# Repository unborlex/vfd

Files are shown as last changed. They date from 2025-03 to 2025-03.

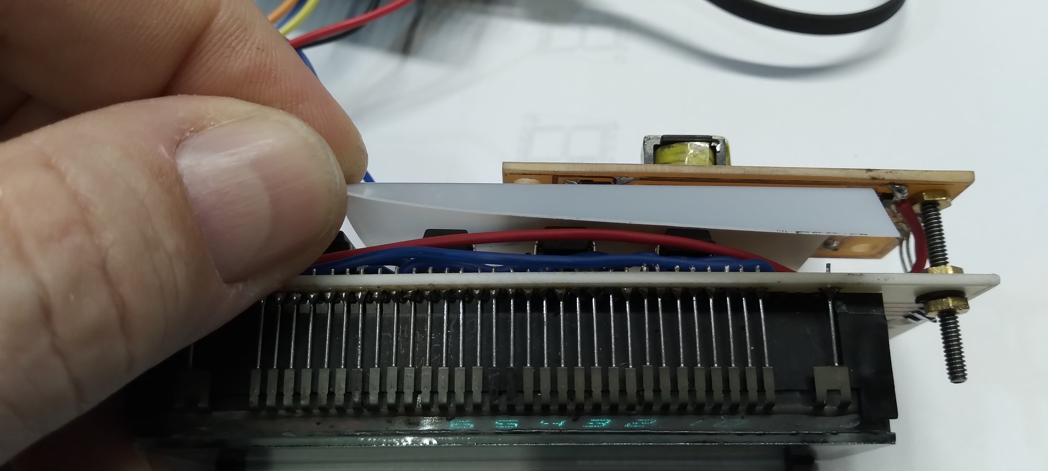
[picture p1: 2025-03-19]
20250319_105229.jpg

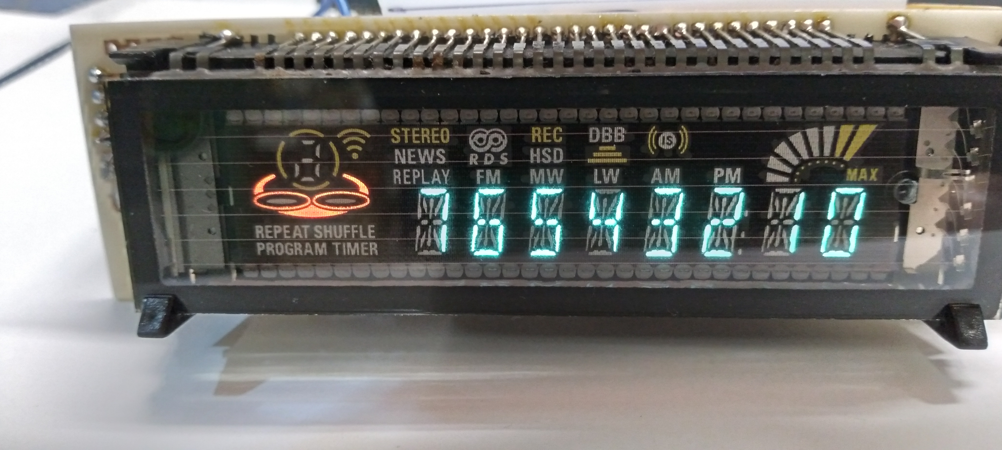
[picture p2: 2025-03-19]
20250319_105207.jpg

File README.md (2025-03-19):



El soft esta generado para arduino, en un ESP32, hay dos funciones principales para escribir en el display solo numeros y una es para escribir 8 digitos mas uno de simbolos 
y otra funcion donde se pueden escribir 4 digitos, en este caso se obtiene el doble de brillo ya que solo se multiplexa por 4.

La electronica consta de registros de dezplazamiento CD4094 funcionando en 18,5V elevando los 5V del ESP32 con un MC34063 y aislando las entradas con transistores para funcionar con 
señales de 3v del ESP32.

El filamento es alimentado con una tension cuadrada bipolar generada por un CD40106 montada sobre los 5V ( de 0,7 a 4,3V ) variable con un potenciometro, este valor queda montado por debajo de los 5v
de esta forma cuando los anodos y las grillas tienen 0v se logra un apagado total de los mismos y con la alterna se logra un brillo mas parejo a lo largo del display.

La tension de 18v tambien puede variarse con un potenciometro, la realidad es que la tension de filamento en mi display hay que mantenerla el maximo y la tension de anados y grilla 
tambien estan al maximo en mi caso 18,5v.

Usando estos integrados no debemos superar los 20V, no llegue a probar esto, esta circuiteria y soft es un prototipo de prueba para este display en particular, otros modelos deberan ser
ensayados con otros tipos de circuitos a medida.
La tension de funcionamiento ideal seria un poco mas elevada 25-35V el problema es que habria que usar un conjunto de transistores y resistencias por pin de anodo y grilla ya que los CMOS se quemarian, multiplicando la electronica demasiado, todo esto para obtener un display que podria ser reemplazado tranquilamente por uno alfanumerico de 2x16 caracterers

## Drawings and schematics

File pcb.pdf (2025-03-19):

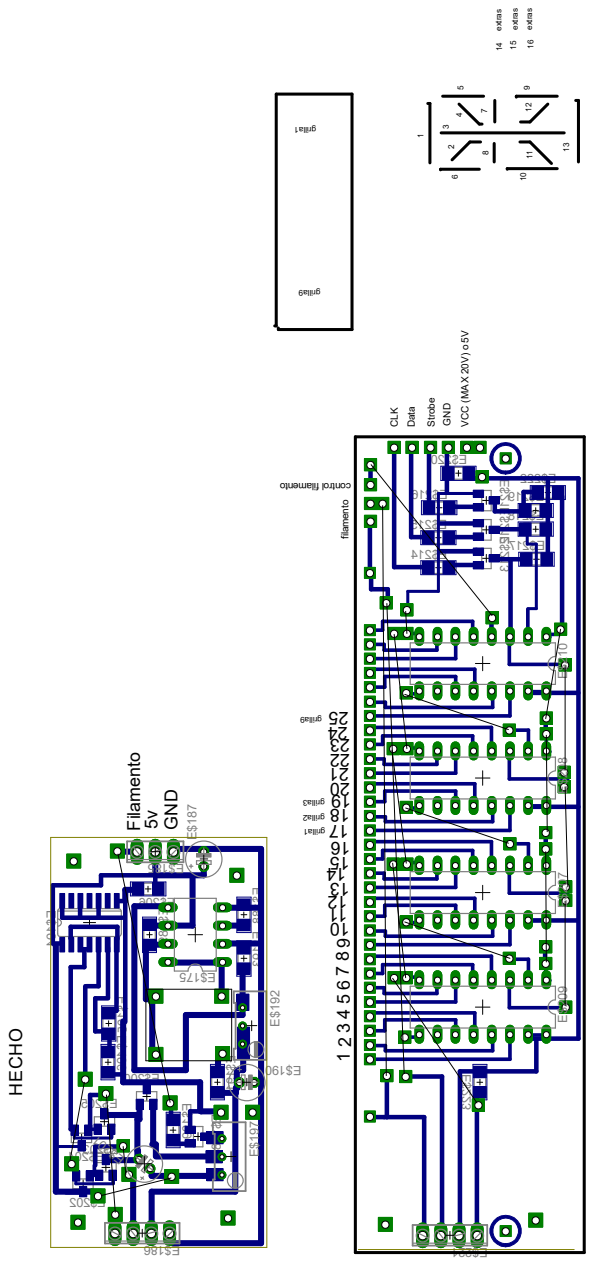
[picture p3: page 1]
grilla1; grilla2; grilla3; grilla9

9 10 11 12 13 141516 extras extras extras

E$221 Filamento 5vGND HECHO filamento control filamento CLK Data Strobe GND VCC (MAX 20V) o 5V

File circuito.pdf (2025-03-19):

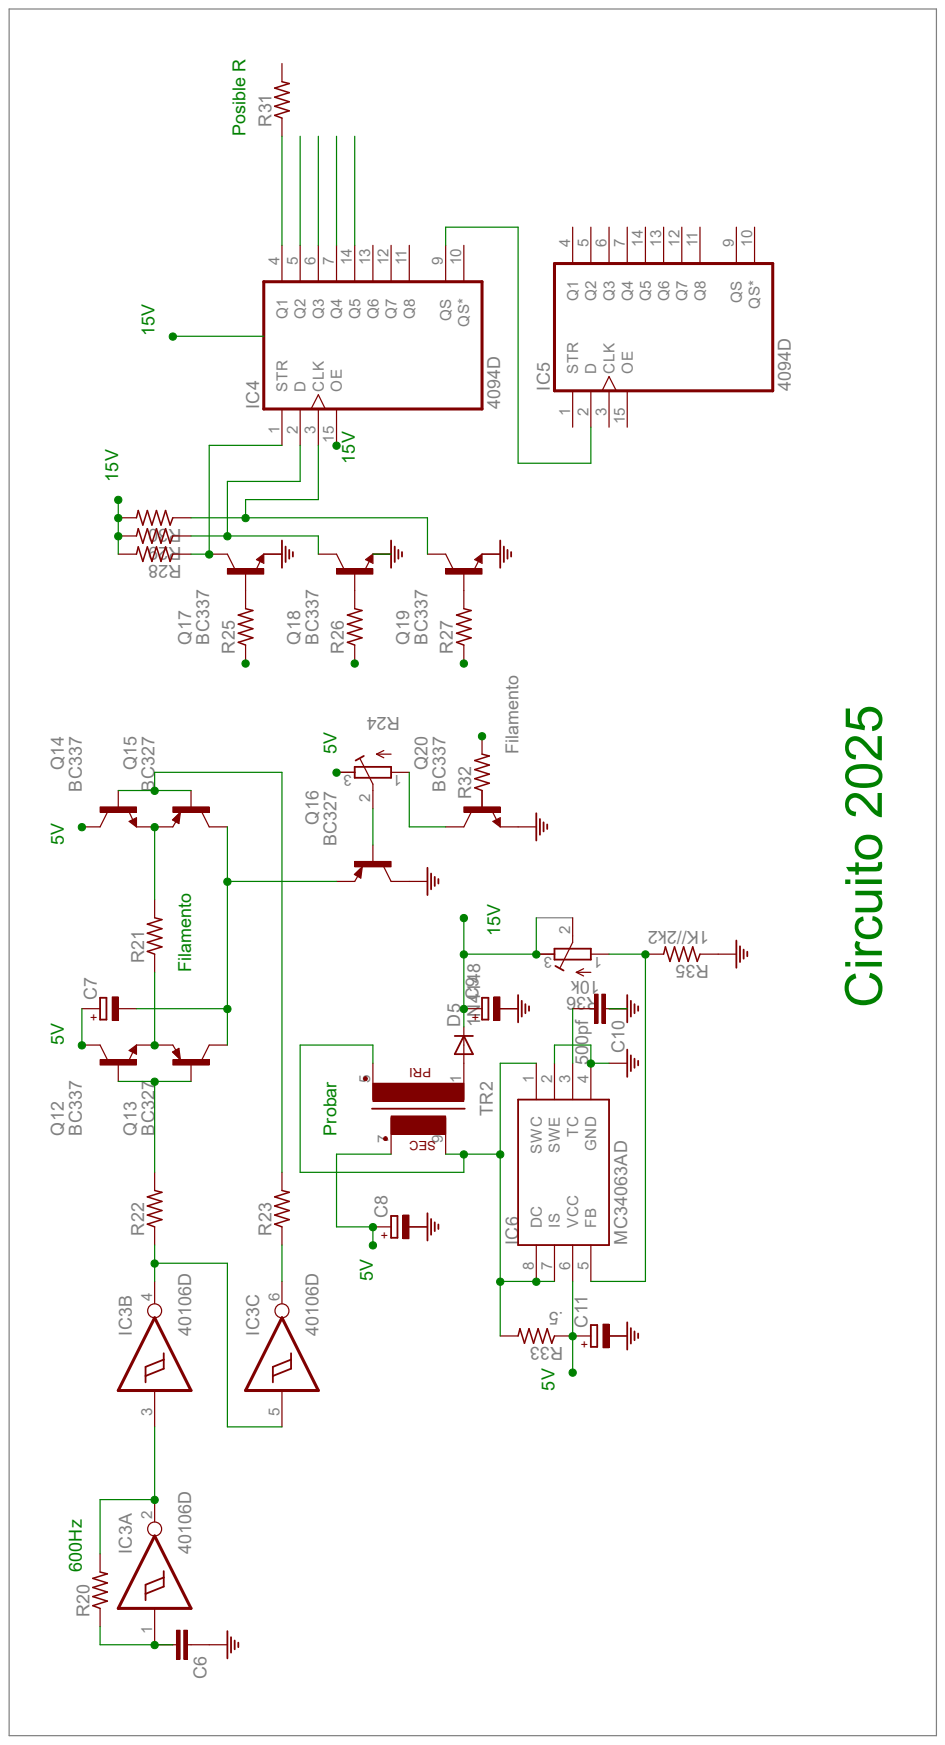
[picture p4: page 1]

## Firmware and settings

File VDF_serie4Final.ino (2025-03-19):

void          demo_var();
void          visualizar9();
void          apagado();
void          visualizar4();


const int vfd_clk = 25;
const int vfd_dat = 26;
const int vfd_str = 27;
unsigned char numeros9[] = {0b00010000,0b01110000,0b01011111,0b01011011,0b00110011,0b01111001,0b01101101,0b00110000, 0b01111110};          // 76543210 => Pabcdefg
unsigned char numeros4[] = {0b00000000,0b00000000,0b00000000,0b00000000,0b00000000,0b01111001,0b01101101,0b00110000, 0b01111110};          // 76543210 => Pabcdefg
int       ind = 0;

void setup()
{
            Serial.begin(115200);
            pinMode(vfd_clk, OUTPUT);  //definir pin como salida
            pinMode(vfd_dat, OUTPUT);  //definir pin como salida
            pinMode(vfd_str, OUTPUT);  //definir pin como salida
            digitalWrite(vfd_clk, HIGH);      // "0"
            digitalWrite(vfd_dat, HIGH);      // "0"
            digitalWrite(vfd_str, HIGH);      // "0"
           
}

void loop()
{
              
                         
                         visualizar9();       // 8 digitos con el brillo minimo  
                         //apagado();
                         //visualizar4();     // 4 digitos con mas billo                       
                         delay(1);
                         
             
}
void          visualizar9()      //posiblemente esten numeradas al reves las grillas
{
                      unsigned char  datos_vis;
                      datos_vis = numeros9[ind];      //  76543210 => Pabcdefg

                      
                      digitalWrite(vfd_dat, HIGH);      // "0" 3
                      demo_var();
                      digitalWrite(vfd_clk, LOW);       // "1"
                      demo_var();
                      digitalWrite(vfd_clk, HIGH);      // "0"

                      digitalWrite(vfd_dat, HIGH);      // "0" 4
                      demo_var();;
                      digitalWrite(vfd_clk, LOW);       // "1"
                      demo_var();
                      digitalWrite(vfd_clk, HIGH);      // "0"

                      digitalWrite(vfd_dat, HIGH);      // "0" 2
                      demo_var();
                      digitalWrite(vfd_clk, LOW);       // "1"
                      demo_var();
                      digitalWrite(vfd_clk, HIGH);      // "0"

                      digitalWrite(vfd_dat, HIGH);      // "0" 
                      if( datos_vis & 0b01000000)    //76543210 => Pabcdefg   ***********  1  a  *****************
                      {
                                    digitalWrite(vfd_dat, LOW);      // "1"                         
                      }
                      demo_var();
                      digitalWrite(vfd_clk, LOW);       // "1"
                      demo_var();
                      digitalWrite(vfd_clk, HIGH);      // "0"

                      digitalWrite(vfd_dat, HIGH);      // "0" 
                      if( datos_vis & 0b00000010)    //76543210 => Pabcdefg   ***********  6  f  *****************
                      {
                                    digitalWrite(vfd_dat, LOW);      // "1"                         
                      }
                      demo_var();
                      digitalWrite(vfd_clk, LOW);       // "1"
                      demo_var();
                      digitalWrite(vfd_clk, HIGH);      // "0"  

                      digitalWrite(vfd_dat, HIGH);      // "0" 
                      if( datos_vis & 0b00100000)    //76543210 => Pabcdefg   ***********  5  b  *****************
                      {
                                    digitalWrite(vfd_dat, LOW);      // "1"                         
                      }
                      demo_var();
                      digitalWrite(vfd_clk, LOW);       // "1"
                      demo_var();
                      digitalWrite(vfd_clk, HIGH);      // "0"
                      
                      digitalWrite(vfd_dat, HIGH);      // "0"      
                      if( datos_vis & 0b00000001)    //76543210 => Pabcdefg   ***********  7 y 8  g  *****************
                      {
                                    digitalWrite(vfd_dat, LOW);      // "1"                         
                      }
                      demo_var();
                      digitalWrite(vfd_clk, LOW);       // "1"                    7
                      demo_var();
                      digitalWrite(vfd_clk, HIGH);      // "0"
                                            
                      demo_var();
                      digitalWrite(vfd_clk, LOW);       // "1"                    8
                      demo_var();
                      digitalWrite(vfd_clk, HIGH);      // "0"

                      digitalWrite(vfd_dat, HIGH);      // "0" 11
                      demo_var();
                      digitalWrite(vfd_clk, LOW);       // "1"
                      demo_var();
                      digitalWrite(vfd_clk, HIGH);      // "0"

                      digitalWrite(vfd_dat, HIGH);      // "0" 12
                      demo_var();
                      digitalWrite(vfd_clk, LOW);       // "1"
                      demo_var();
                      digitalWrite(vfd_clk, HIGH);      // "0"

                      digitalWrite(vfd_dat, HIGH);      // "0" 
                      if( datos_vis & 0b00000100)    //76543210 => Pabcdefg   ***********  10  e  *****************
                      {
                                    digitalWrite(vfd_dat, LOW);      // "1"                         
                      }
                      demo_var();
                      digitalWrite(vfd_clk, LOW);       // "1"
                      demo_var();
                      digitalWrite(vfd_clk, HIGH);      // "0"
                      
                      digitalWrite(vfd_dat, HIGH);      // "0" 
                      if( datos_vis & 0b00010000)    //76543210 => Pabcdefg   ***********  9  c  *****************
                      {
                                    digitalWrite(vfd_dat, LOW);      // "1"                         
                      }
                      demo_var();
                      digitalWrite(vfd_clk, LOW);       // "1"
                      demo_var();
                      digitalWrite(vfd_clk, HIGH);      // "0"

                      digitalWrite(vfd_dat, HIGH);      // "0" 14
                      demo_var();
                      digitalWrite(vfd_clk, LOW);       // "1"
                      demo_var();
                      digitalWrite(vfd_clk, HIGH);      // "0"    

                      digitalWrite(vfd_dat, HIGH);      // "0" 
                      if( datos_vis & 0b00001000)    //76543210 => Pabcdefg   ***********  13  d  *****************
                      {
                                    digitalWrite(vfd_dat, LOW);      // "1"                         
                      }
                      demo_var();
                      digitalWrite(vfd_clk, LOW);       // "1"
                      demo_var();
                      digitalWrite(vfd_clk, HIGH);      // "0"

                      digitalWrite(vfd_dat, HIGH);      // "0" 15
                      demo_var();
                      digitalWrite(vfd_clk, LOW);       // "1"
                      demo_var();
                      digitalWrite(vfd_clk, HIGH);      // "0"

                      digitalWrite(vfd_dat, HIGH);      // "0" 16
                      demo_var();
                      digitalWrite(vfd_clk, LOW);       // "1"
                      demo_var();
                      digitalWrite(vfd_clk, HIGH);      // "0"

                      //****************** grillas **********************

                      digitalWrite(vfd_dat, HIGH);      // "0" 
                      if( ind == 2 )  //***********  19  grilla 3  *****************
                      {
                                    digitalWrite(vfd_dat, LOW);      // "1"                         
                      }
                      demo_var();
                      digitalWrite(vfd_clk, LOW);       // "1"
                      demo_var();
                      digitalWrite(vfd_clk, HIGH);      // "0"

                      digitalWrite(vfd_dat, HIGH);      // "0" 
                      if( ind == 3 )  //***********  20  grilla 4  *****************
                      {
                                    digitalWrite(vfd_dat, LOW);      // "1"                         
                      }
                      demo_var();
                      digitalWrite(vfd_clk, LOW);       // "1"
                      demo_var();
                      digitalWrite(vfd_clk, HIGH);      // "0"

                      digitalWrite(vfd_dat, HIGH);      // "0" 
                      if( ind == 1 )  //***********  18  grilla 2  *****************
                      {
                                    digitalWrite(vfd_dat, LOW);      // "1"                         
                      }
                      demo_var();
                      digitalWrite(vfd_clk, LOW);       // "1"
                      demo_var();
                      digitalWrite(vfd_clk, HIGH);      // "0"

                      digitalWrite(vfd_dat, HIGH);      // "0" 
                      if( ind == 0 )  //***********  17  grilla 1  *****************
                      {
                                    digitalWrite(vfd_dat, LOW);      // "1"                         
                      }
                      demo_var();
                      digitalWrite(vfd_clk, LOW);       // "1"
                      demo_var();
                      digitalWrite(vfd_clk, HIGH);      // "0"

                      digitalWrite(vfd_dat, HIGH);      // "0" 
                      if( ind == 5 )  //***********  22  grilla 6  *****************
                      {
                                    digitalWrite(vfd_dat, LOW);      // "1"                         
                      }
                      demo_var();
                      digitalWrite(vfd_clk, LOW);       // "1"
                      demo_var();
                      digitalWrite(vfd_clk, HIGH);      // "0"

                      digitalWrite(vfd_dat, HIGH);      // "0" 
                      if( ind == 4 )  //*********** 21  grilla 5  *****************
                      {
                                    digitalWrite(vfd_dat, LOW);      // "1"                         
                      }
                      demo_var();
                      digitalWrite(vfd_clk, LOW);       // "1"
                      demo_var();
                      digitalWrite(vfd_clk, HIGH);      // "0"

                      digitalWrite(vfd_dat, HIGH);      // "0" 
                      if( ind == 6 )  //***********  23  grilla 7  *****************
                      {
                                    digitalWrite(vfd_dat, LOW);      // "1"                         
                      }
                      demo_var();
                      digitalWrite(vfd_clk, LOW);       // "1"
                      demo_var();
                      digitalWrite(vfd_clk, HIGH);      // "0"

                      digitalWrite(vfd_dat, HIGH);      // "0" 
                      if( ind == 7 )  //***********  24  grilla 8  *****************
                      {
                                    digitalWrite(vfd_dat, LOW);      // "1"                         
                      }
                      demo_var();
                      digitalWrite(vfd_clk, LOW);       // "1"
                      demo_var();
                      digitalWrite(vfd_clk, HIGH);      // "0"

                      digitalWrite(vfd_dat, HIGH);      // "0" 27
                      demo_var();
                      digitalWrite(vfd_clk, LOW);       // "1"
                      demo_var();
                      digitalWrite(vfd_clk, HIGH);      // "0"

                      digitalWrite(vfd_dat, HIGH);      // "0" 28
                      demo_var();
                      digitalWrite(vfd_clk, LOW);       // "1"
                      demo_var();
                      digitalWrite(vfd_clk, HIGH);      // "0"

                      digitalWrite(vfd_dat, HIGH);      // "0" 26
                      demo_var();
                      digitalWrite(vfd_clk, LOW);       // "1"
                      demo_var();
                      digitalWrite(vfd_clk, HIGH);      // "0"

                      digitalWrite(vfd_dat, HIGH);      // "0" 
                      if( ind == 8 )  //***********  25  grilla 9  *****************
                      {
                                    digitalWrite(vfd_dat, LOW);      // "1"                         
                      }
                      demo_var();
                      digitalWrite(vfd_clk, LOW);       // "1"
                      demo_var();
                      digitalWrite(vfd_clk, HIGH);      // "0"
    
                      digitalWrite(vfd_dat, HIGH);      // "0" 30
                      demo_var();
                      digitalWrite(vfd_clk, LOW);       // "1"
                      demo_var();
                      digitalWrite(vfd_clk, HIGH);      // "0"
                  
                      digitalWrite(vfd_dat, HIGH);      // "0" 29
                      demo_var();
                      digitalWrite(vfd_clk, LOW);       // "1"
                      demo_var();
                      digitalWrite(vfd_clk, HIGH);      // "0"  
  
                      digitalWrite(vfd_dat, HIGH);      // "0" 31
                      demo_var();
                      digitalWrite(vfd_clk, LOW);       // "1"
                      demo_var();
                      digitalWrite(vfd_clk, HIGH);      // "0"        

                      digitalWrite(vfd_dat, LOW);      // "0"    FILAMENTO
                      demo_var();
                      digitalWrite(vfd_clk, LOW);       // "1"
                      demo_var();
                      digitalWrite(vfd_clk, HIGH);      // "0"        
                      demo_var();
                      digitalWrite(vfd_dat, LOW);      // "0"    
                        
                      //********** genero STROBE *****************
                      demo_var();
                      digitalWrite(vfd_str, LOW);      // "1       GENERO STROBE     
                      demo_var();
                      digitalWrite(vfd_str, HIGH);      // "0"
                      demo_var();
                      // *********** incremento de puntero a datos y grilla    
                      ind++;
                      if(ind >= 9 )
                      {
                                ind = 0;
                      }
                      
  
}
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
